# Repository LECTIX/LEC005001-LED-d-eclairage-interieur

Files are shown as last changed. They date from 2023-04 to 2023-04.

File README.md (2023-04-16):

# LEC005001 - LED d’éclairage intérieur
Fichiers sources pour le produit LEC005001

## Description du produit

Éclairez un batiment ou une partie d'un batiment à l'aide de ce petit circuit possédant led et résistances.
- **BLANC** ton froid
- **ALIMENTATION** 5 à 16 V DC
- **RÉSISTANCE** de 500 ohm intégrée
- **PRATIQUE** s’intégre facilement dans les maquettes
- **FIXATION** avec vis ou ruban double face

## Applications

- Éclairage intérieur complet d’un petit batiment.
- Éclairage d’une pièce spécifique d’un batiment.

## Installation

L’installation est simple et rapide :

1.Souder des fils sur les bornes + et -.
1.Installer la led dans la maquette à éclairer à l’aide de petites vis ou de ruban double face.
1.Faire ressortir les fils de la maquette.
1.Brancher sur une alimentation de moins de 16 V DC.
1.Profitez d’une nouvelle dimension dans l’éclairage des batiments de votre réseau.

## Utiliser les fichiers sources pour fabriquer le produit

Il n'est **pas nécessaire de savoir souder ou d'être bon en électronique** pour se procurer ce produit. Grâce aux fichiers sources publiés ici, vous pouvez être en mesure de faire fabriquer ce produit par un sous traitant.

### Faire fabriquer chez un sous traitant

Il est aujourd'hui possible de faire fabriquer à moindre cout des cartes électroniques. Nous recommendons [JLCPCB](https://jlcpcb.com/) si vous voulez aller au moins cher. Si vous préférez un acteur européen, [eurocircuits](https://www.eurocircuits.com/) est un des acteurs reconnus.

IMAGE ALT TEXT (http://www.youtube.com/watch?v=RXGGvsUtz0c "TUTO : faire fabriquer un produit LECTIX")

1. Télécherger les sources de ce produit en cliquant sur le bouton `Code`, puis `Download ZIP`.
1. Décompresser le dossier.
1. Les fichiers pour la fabrication se trouvent dans le répertoire `hardware/prod`.
1. Se connecter sur [https://cart.jlcpcb.com/quote](https://cart.jlcpcb.com/quote)
1. Cliquer sur le bouton `Add gerber file` et sélectionner le fichier `gerbers.zip`.
1. Sélectionnez la quantité de cartes que vous souhaitez dans le champs `PCB Qty`.
1. Laisser toutes les autres options par défaut, puis cliquez sur le toggle switch en face de `PCB Assembly`, et enfin sur le bouton `confirm`.
1. Une preview de la carte électronique sans les composants doit apparaitre. Cliquez sur `NEXT`.
1. Cliquez sur le bouton `Add BOM File`, puis sélectionnez le fichier `bom.csv`
1. Cliquez sur le bouton `Add CPL File`, puis sélectionnez le fichier `pos.csv`
1. **Vérifier que tous les composants sont en stock** et bien sélectionnés, puis cliquez sur `NEXT`.
1. Une preview de la carte avec ses composants apparait. Continuer le chemin en cliquant sur `NEXT`.
1. Le prix final apparait. Sélectionnez la catégorie du produit, puis cliquez sur `SAVE TO CART`.
1. Une fois sauvegardé dans votre panier, vous pouvez valider votre commande et choisir le moyen d'acheminement. Afin de ne pas avoir à se préoccuper des frais de douane, nous vous conseillons de choisir une méthode d'expédition DDP.

Vous receverez vos cartes sous 1 à 3 semaines. 

**Nous ne sommes en aucun cas responsables des cartes qui arriveraient défectueuses ou non fonctionnelles.**

### Modifications des fichiers sources

Installez kicad 6 (ou version supérieure), et ouvrez le fichier LEC005001.kicad_pro

### Regénérer les fichiers gerber, BOM, et position (Optionnel)

Peut se faire simplement en utilisant kikit :

```
cd hardware

# generate PCB panel (panel config can be change in panel-config.json)
docker run --rm -w /kikit -v $PWD:/kikit yaqwsx/kikit kikit panelize -p panel-config.json LEC005001.kicad_pcb LEC005001-panel.kicad_pcb

# generate assembly files
docker run --rm -w /kikit -v $PWD:/kikit yaqwsx/kikit kikit fab jlcpcb --assembly --no-drc --schematic LEC005001.kicad_sch --field LCSC --corrections JLCPCB_CORRECTION --nametemplate LEC005001_{} LEC005001-panel.kicad_pcb prod/

```

## License
Tous nos fichiers sont plubliés sous la license CERN Open Hardware Licence Version 2 - Strongly Reciprocal

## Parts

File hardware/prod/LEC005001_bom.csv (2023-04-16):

Comment | Designator | Footprint | LCSC
LED | D1 | LED_SMD:LED_0603_1608Metric | C2290
1k | R1,R2 | Resistor_SMD:R_0805_2012Metric | C17513

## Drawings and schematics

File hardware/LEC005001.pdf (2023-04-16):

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

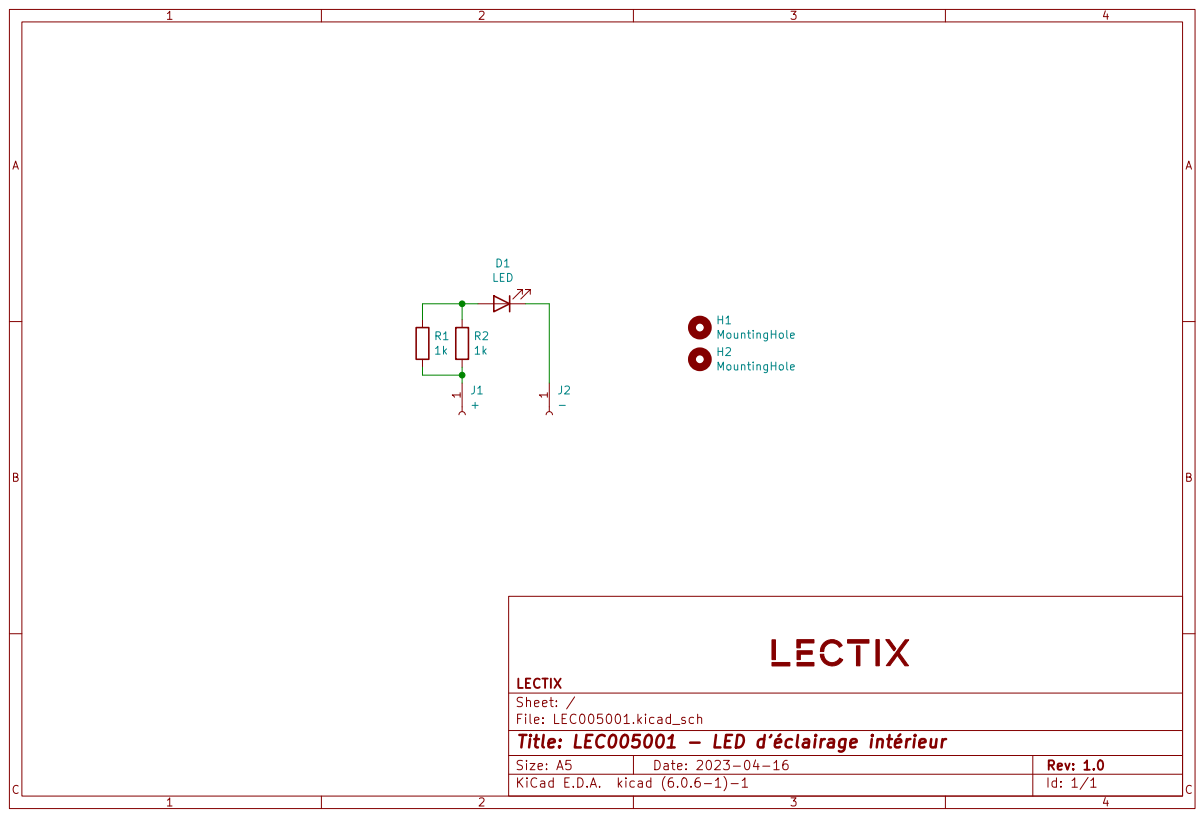
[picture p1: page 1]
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

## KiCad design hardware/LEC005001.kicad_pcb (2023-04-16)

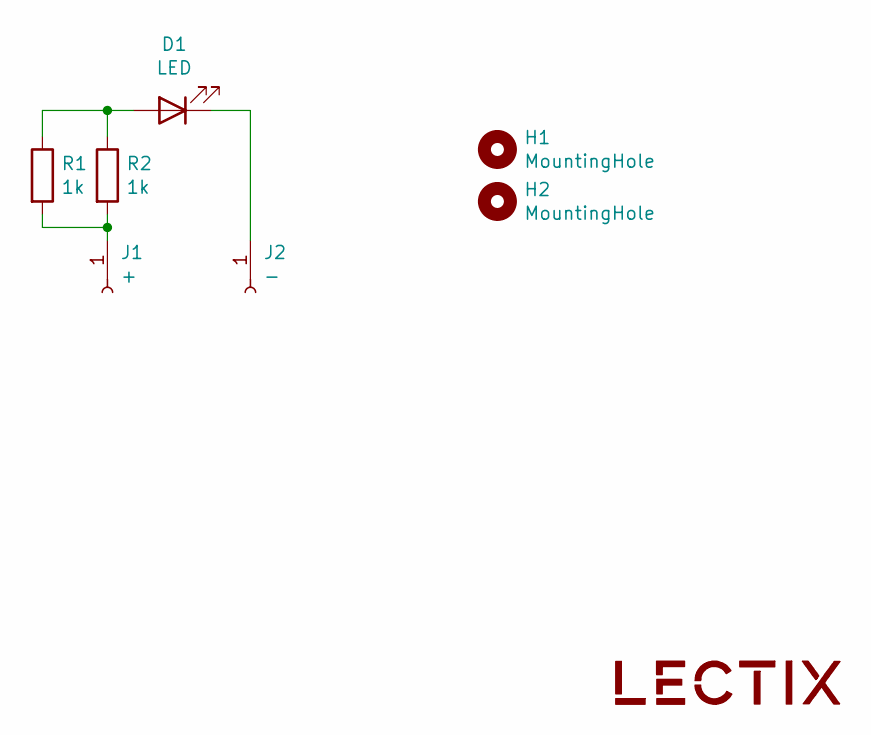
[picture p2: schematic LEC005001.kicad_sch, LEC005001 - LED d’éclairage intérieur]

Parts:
D1: LED; LED_0603_1608Metric; LCSC C2290
H1, H2: MountingHole; MountingHole_3.2mm_M3
J1: +; TestPoint_Pad_2.0x2.0mm
J2: -; TestPoint_Pad_D2.0mm
LOGO1: logo_lectix_25mm; Logo_10mm
R1, R2: 1k; R_0805_2012Metric; LCSC C17513

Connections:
unnamed: D1.1 (K), J2.1
unnamed: D1.2 (A), R1.1, R2.1
unnamed: J1.1, R1.2, R2.2

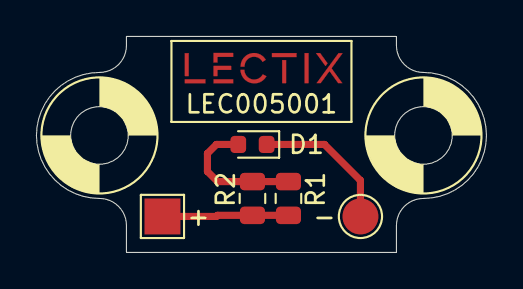
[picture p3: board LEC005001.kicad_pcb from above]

Board: 2 copper layers, 25.0 x 12.0 mm, 8 parts (0 on the bottom side), 3 nets.

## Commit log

2023-04-16 Add kicad source files + gerbers
    [LEC005001-CmtUser.gbr, LEC005001-CuBottom.gbl, LEC005001-CuTop.gtl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]
2023-04-16 Add panel prod file
    [LEC005001-CmtUser.gbr, LEC005001-CuTop.gtl, LEC005001-EdgeCuts.gm1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]
